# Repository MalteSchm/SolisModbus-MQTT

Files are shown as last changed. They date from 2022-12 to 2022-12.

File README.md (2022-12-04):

# SolisModbus-MQTT

## Introduction
Bridge between Solis/ Ginlong inverters and MQTT based on ESP8266. The inverter data is read from the RS-485 interface and send over WiFi to a connected MQTT broker.
Tested with Solis S6-GR1P1K-M

Based on code from jimmyburnworld (https://github.com/jimmyburnworld/SolisModbus-MQTT), October 2022. Changes: 

- Use correct Modbus registers of my inverter model. 
- Limited information export 
- Use JSON data in single MQTT topic
- Code cleanups

## Hardware

The ESP8266 is interfaced with the Solis inverter using RS-485 available on the inverters 'COM' port. COM port pinout is 1 = +5Vcc, 2 = 0V com, 3 = 'A' 4 = 'B'. Please note that this might vary by model and it is your responsibility to check before connecting. 

I used a MAX3485 to interface the ESP8266 to the RS-485 port. The MAX3485 is 3.3V compatible. MAX485 may work as well based on some sources in the internet but is 5V logic so your milage may vary.

MAX3485 connection

- Pin 1 RO - ESP8266 Pin D7
- Pin 2, 3, RE, DE  - ESP8266 Pin D5 
- Pin 4 DI - ESP8266 Pin D6
- Pin 5 GND - ESP8266 GND and Ginlong inverter Pin 2 
- Pin 6 A - Ginlong inverter Pin 3
- Pin 7 B - Ginlong inverter Pin 4
- Pin 8 Vcc - ESP8266 3.3V pin

The hardware is pretty basic. Note that:

- there is a 120Ohm resistor between A and B to terminate the RS-485 line 
- two status indicator LEDs in series to a 220 Ohm resistor are connected to the ESP8266 D8 and D0 pins
- I got the plug to connect to the inverter off ebay

STLs for the case can be found in the "case" folder in this repository.

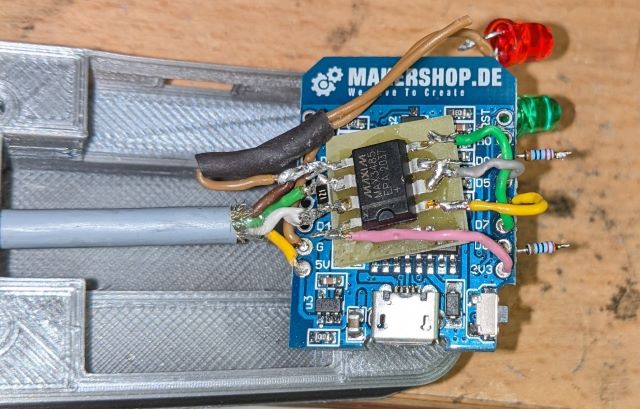
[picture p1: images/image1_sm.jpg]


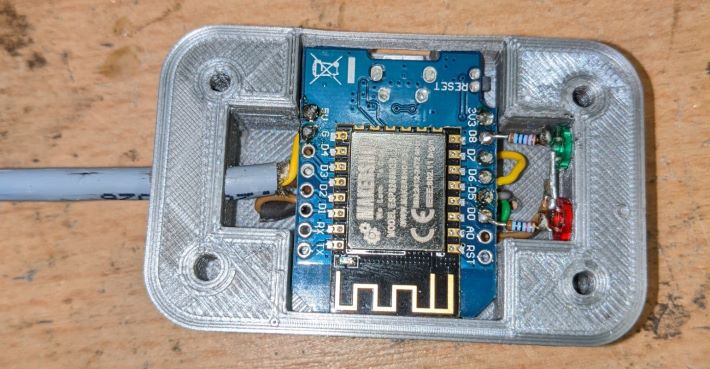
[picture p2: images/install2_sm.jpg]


## Software

Install via Arduino. Make sure to configure ESP8266 support and install the required libraries (ArduinoMqttClient, ArduionoJson, EspSoftwareSerial, ModbusMaster, ESP8266WiFi).
You need to configure:

- Wifi access credentials
- MQTT broker information and credentials

## Installation

Set inverter 'address' to 2 - check communications to BMS and Meter after doing this before proceeding
to connect ESP8266.

## Known issues:

Signed 16bit values and 32bit values do not work correctly.
The signed 16bit values are unsigned because the ModbusMaster library only returns uint16_t type.
32bit values are due to word/ byte swapping Endian-ness etc. I tried to fix this but don't have a good way of testing as none of the info makes use of more then 16bit
Only included the variables for this project, feel free to add more or remove
Search for RS485_MODBUS-Hybrid-BACoghlan-201811228-1854.pdf for protocol description and registers

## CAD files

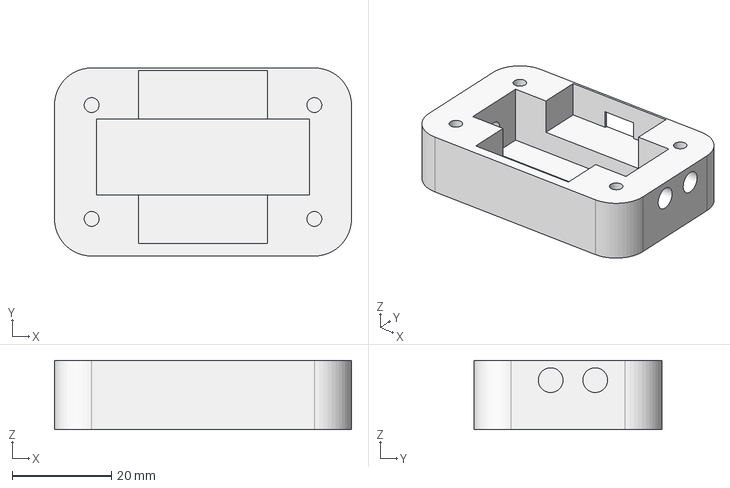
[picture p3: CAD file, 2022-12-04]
case/Gehäuse_u.stp
60.0 x 38.0 x 14.0 mm

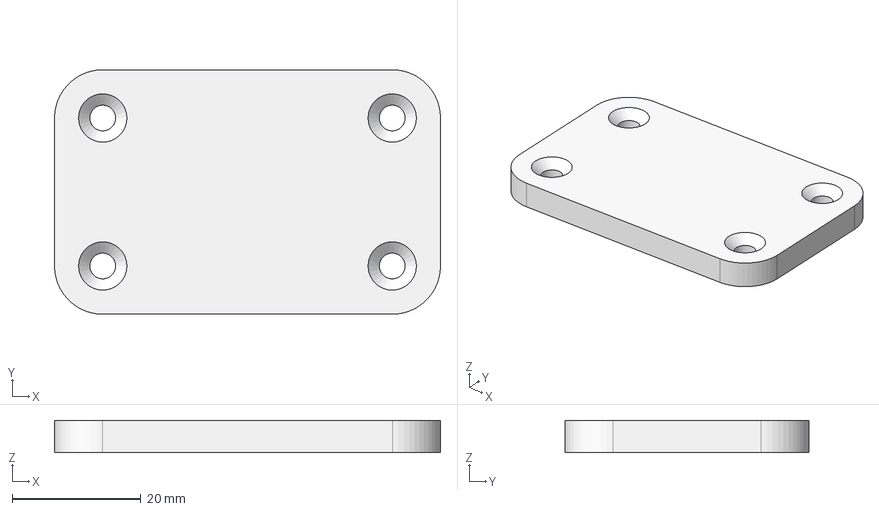
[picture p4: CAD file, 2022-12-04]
case/Gehäuse_o.stp
60.0 x 38.0 x 5.00 mm

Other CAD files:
case/Gehäuse_o.stl
case/Gehäuse_u.stl

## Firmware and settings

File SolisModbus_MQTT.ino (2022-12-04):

/*
  jimmyburnworld, October 2022
  SolisModbus-MQTT Bridge using ESP8266 based controller
  Uses ModbusMaster and SoftwareSerial libraries for the RS485/ Modbus side of things
  ESP8266WiFi and ArduinoMqttCLient for the MQTT side
  https://github.com/jimmyburnworld/SolisModbus-MQTT
  Uses Solis inverter 'COM' port. Set inverter 'address' to 2 - check communications to BMS and Meter after doing this before proceeding
  to connect Arduino.
  COM port: 1 = +5Vcc, 2 = 0V com, 3 = 'A' 4 = 'B' - This might vary by model, your responsibility to check before connecting
  MAX485 GND needed to be connected to 'G' next to 3.3V pin to work.
  Used inverter +5V and 0V to power ESP8266 using 'Vin' and 'G' connections & jumpered to MAX485 Vcc & Gnd
  KNOWN ISSUES: Signed 16bit values and 32bit values do not work correctly.
  Thee signed 16bit values are unsigned because the ModbusMaster library only returns uint16_t type.
  32bit values are due to word/ byte swapping Endian-ness etc.
  Only included the variables for this project, feel free to add more or remove
  Search for RS485_MODBUS-Hybrid-BACoghlan-201811228-1854.pdf for protocol description and registers
*/

#include <ModbusMaster.h>
#include <ESP8266WiFi.h>
#include <ArduinoMqttClient.h>
#include <SoftwareSerial.h>
#include <ArduinoJson.h>

// *************************************************************************************

// WIFI settings
#define WIFI_SSID ""    // YOUR SSID goes here
#define WIFI_PASSWORD ""   // YOUR WIFI PASSWORD goes here

// MQTT Broker settings. Will work with IP or local name. Static IP is more reliable
#define MQTT_BROKER_URL  "beaglebone" //"xxx.xxx.xxx.xxx"; //"core-mosquitto";
#define MQTT_BROKER_PORT 1883         //your port here
#define MQTT_TOPIC "Solis/inverter"
#define MQTT_CLIENT_ID "SolisInv"
#define MQTT_USERNAME "your user"
#define MQTT_PASSWORD "your password"

// Pin definitions
#define LED_GR 15     // Green LED Pin
#define LED_RT 16     // Red LED Pin
#define MAX485_RX 12  // connect RX to D6 (ESP2866 D6), TX to D7 (ESP2866 D7)
#define MAX485_TX 13
#define MAX485_DE 14  // Use a MAX485 compatible transceiver, bridge DE and RE_NEG and connect to D5 on ESP8266

// *************************************************************************************

// receivePin, transmitPin, inverse_logic, bufSize, isrBufSize
SoftwareSerial S(MAX485_RX, MAX485_TX);

// instantiate ModbusMaster object
ModbusMaster node;

//*MQTT Initialisation here
WiFiClient wifiClient;
MqttClient mqttClient(wifiClient);

// Callbacks for setting the MAX485 to send or receive
void preTransmission()
{
  digitalWrite(MAX485_DE, 1);
}

void postTransmission()
{
  digitalWrite(MAX485_DE, 0);
}

const char broker[] = MQTT_BROKER_URL; 
int        port     = MQTT_BROKER_PORT; 
int count = 0;

#define REGISTERS_TO_READ 9
// Reg 3005 - Active power U32 - TBD: My inverter output power is not high enough to test if this value is read correctly
// Reg 3009 - Total energy U32 - TBD: Could not be tested
// Reg 3015 - Energy yesterday U16 - Manual says 3015 is Energy today
// Reg 3016 - Energy today U16 - Manual says 3015 is Energy yesterday
// Reg 3011 - Energy this month U32 - TBD: Could not be tested
// Reg 3013 - Energy last month U32 - TBD: Could not be tested
// Reg 3017 - Energy this year U32
// Reg 3019 - Energy last year U32
// Reg 3042 - Inverter temp U16

const long RegAddress[REGISTERS_TO_READ] = {3005, 3009, 3016, 3015, 3011, 3013, 3017, 3019, 3042};
const int  RegWords[REGISTERS_TO_READ]   = {   2,    2,    1,    1,    1,    1,    1,    1,    1};
const float RegScalar[REGISTERS_TO_READ] = { 1.0,  1.0,  0.1,  0.1,  1.0,  1.0,  1.0,  1.0,0.001};
float RegValue[REGISTERS_TO_READ];
uint8_t RegResult[REGISTERS_TO_READ];

// Initialise character arrays with JSON names
const char *RegName[REGISTERS_TO_READ] = 
                  {"PACTot",
                   "ETotal",
                   "EToday",
                   "EYesterday",
                   "EMonth",
                   "ELastMonth",
                   "EYear",
                   "ELastYear",
                   "InvTemperature",
                  };

void setup()
{
  pinMode(LED_GR, OUTPUT);
  pinMode(LED_RT, OUTPUT);
  pinMode(MAX485_DE, OUTPUT);
  digitalWrite(LED_GR, 0);    // LED off
  digitalWrite(LED_RT, 0);    // LED off
  digitalWrite(MAX485_DE, 0); // Init in receive mode

  // Modbus communication runs at 9600 baud
  S.begin(9600, SWSERIAL_8N1);

  //Serial Monitor
  Serial.begin(57600);

  // Modbus slave ID 2
  node.begin(2, S); 
  
  // Set callbacks for setting R/W direction on MAX485
  node.preTransmission(preTransmission);
  node.postTransmission(postTransmission);

  //WiFi Connection here
  {
    WiFi.begin(WIFI_SSID, WIFI_PASSWORD);

    Serial.print("Connecting");
    while (WiFi.status() != WL_CONNECTED)
    {
      delay(500);
      Serial.print(".");
      digitalWrite(LED_GR, millis() / 1000 % 2);
    }
    Serial.println();

    digitalWrite(LED_RT, 0);
    digitalWrite(LED_GR, 1);

    Serial.print("Connected, IP address: ");
    Serial.println(WiFi.localIP());
  }

  //MQTT Connection here

  // Each client must have a unique client ID
  mqttClient.setId(MQTT_CLIENT_ID);

  // You can provide a username and password for authentication
  mqttClient.setUsernamePassword(MQTT_USERNAME, MQTT_PASSWORD);
  Serial.print("Attempting to connect to the MQTT broker: ");
  Serial.println(broker);

  if (!mqttClient.connect(broker, port)) {
    Serial.print("MQTT connection failed! Error code = ");
    Serial.println(mqttClient.connectError());
    digitalWrite(LED_RT, 1);
    // FIXME: This is not ideal as it will prevent startup if the MQTT broker becomes active after the inverter
    // Since the inverter will shut down on sunset we will eventually establish a connection the next day
    while (1);
  }

  Serial.println("You're connected to the MQTT broker!");
  Serial.println();

}

void loop()
{
  int RegNo;

  // Update Wifi status indication 
  if (WiFi.status() == WL_CONNECTED) {
    digitalWrite(LED_GR, 1);
  } else {
    digitalWrite(LED_GR, 0);
  }

  //*MQTT Loop
  // call poll() regularly to allow the library to send MQTT keep alives which
  // avoids being disconnected by the broker
  mqttClient.poll();

  // Read inverter registers
  bool error = false;
  for (RegNo = 0; RegNo < REGISTERS_TO_READ; RegNo++) {
    
    RegResult[RegNo] = node.readInputRegisters(RegAddress[RegNo], 10);  // We some extra register as otherwise the actual value is reported in RegResult[RegNo]
    if (RegResult[RegNo] == node.ku8MBSuccess) {
      if (RegWords[RegNo] == 1) {
        RegValue[RegNo] = (node.getResponseBuffer(0) * RegScalar[RegNo]);
      }
      if (RegWords[RegNo] == 2) {
        RegValue[RegNo] = (((node.getResponseBuffer(1) << 16) + node.getResponseBuffer(0)  ) * RegScalar[RegNo]);
      }

      yield();
      delay(500); // Frame interval is 300ms as per Ginlong docu. I found it more stable with 500ms
    } else {
      error = true;
      digitalWrite(LED_RT, 1);
      Serial.println("Error reading inverter registers");     

      StaticJsonDocument<200> jsonDoc;
      jsonDoc["Register"] = RegNo;
      jsonDoc["ErrorCode"] = RegValue[RegNo];
      mqttClient.beginMessage(MQTT_TOPIC);
      serializeJson(jsonDoc, Serial);
      serializeJson(jsonDoc, mqttClient);
      mqttClient.endMessage();
 
    }
  }
  
  Serial.println("Mqtt check");
  // Check error status and tranmit MQTT message
  if (!error) {
    Serial.println("MQTT transmission:");      

    // Create JSON
    StaticJsonDocument<200> jsonDoc;
    for (RegNo = 0; RegNo < REGISTERS_TO_READ; RegNo++)
    {
      jsonDoc[RegName[RegNo]] = RegValue[RegNo];
    }

    // Send JSON as MQTT an on the serial connection
    mqttClient.beginMessage(MQTT_TOPIC);
    serializeJson(jsonDoc, Serial);
    serializeJson(jsonDoc, mqttClient);
    mqttClient.endMessage();

    // indicate things are o.k.
    digitalWrite(LED_RT, 0);
  }

}
